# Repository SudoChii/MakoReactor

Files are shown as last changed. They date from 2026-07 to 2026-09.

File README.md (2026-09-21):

# Mako Reactor

CAD-as-code for layered leverless ("hitbox" style) fight controllers.

Describe where the buttons go, and Mako Reactor gives you back a stack of flat
plates you can send to a laser cutter, router, or 3D printer.

```python
import makoreactor as mr
from affine import Affine
from cadquery import exporters

layout = mr.FgcLeverless()
layout.layout_affine = Affine.translation(0, -13)

stack = mr.f1CapMako1.set(
    width=mr.in2mm(11.8),
    height=mr.in2mm(5),
    hole_deltax=300,
    layout=layout,
)

for i, plate in enumerate(stack.generate()):
    exporters.export(plate.edges(">Z"), f"layer{i}.dxf")
```

Or from a shell:

```bash
python -m makoreactor --layout fgc --width 11.8 --height 5 -o build/
```

## Install

Everything is available from conda-forge, so a single environment file covers it:

```bash
# replace mamba with conda if you don't have mamba
mamba env create -f environment.yml
mamba activate mako

pip install -e .
```

If you'd rather use pip alone, `pip install -e .` pulls `cadquery`, `numpy`, and
`affine` from PyPI; CadQuery ships the OpenCascade binaries as wheels.

Check it works:

```bash
pytest
```

## How it fits together

### Layouts (`makoreactor/layouts.py`)

A `Layout` holds button centres grouped by hand and function — `left_homerow`,
`right_homerow`, `left_thumb`, `right_thumb`, `misc` — and one affine per group
placing it on the plate. `layout_affine` shifts the whole cluster at once.

| layout | buttons | notes |
| --- | --- | --- |
| `CircleCapLeverless` | 20 | smash layout, Frame 1 circular caps |
| `Gccmx` | 22 | as above plus home/share, mimics Crane's GCCMX |
| `SquareCapLeverless` | 20 | smash layout, square MX keycaps |
| `Mako1Hadoe` | 20 | as above, right-hand eight dropped onto the home row |
| `WideGc` | 18 | as `Gccmx`, two thumb buttons a hand, no left pinky |
| `FgcLeverless` | 15 | traditional fighting-game layout, one thumb button |
| `SanwaFgcLeverless` | 15 | as above, spread out for 24/30mm Sanwa buttons |
| `FgcPlus` | 16 | as above on the smash spacing, pinky and two thumbs a hand, all 24mm |

The eight action buttons sit in two rows 22mm apart. In the smash layouts the
*bottom* row lines up with the four directionals, so the fingers rest low and
reach up; `Mako1Hadoe` drops the whole cluster by that one row pitch so the
*top* row lands on the home row instead.

`WideGc` keeps the smash spacing and the right hand's eight, and changes the
other three groups. The stock thumbs are lopsided — two buttons on the left, a
five-button c-stick on the right — so it cuts the right cluster back to its
bottom two, the same pair the left thumb already has, and both thumbs end up
with the same reach. The centre is Crane's, inherited from `Gccmx`: a row of
three on a 20mm pitch where the stock layout has one button. The left hand
loses its pinky — the outermost of its four, the same button `FgcLeverless`
drops — leaving three directionals. Eighteen buttons.

Dropping the pinky leaves the cluster 13mm right of the plate centre, since
nothing came off the right hand. Shift it back with
`layout.layout_affine = Affine.translation(-13.3, 0)` if that matters for the
plate you are cutting.

`layout.layout` is the flat list of centres in plate coordinates;
`layout.geom` is the same thing as cap outlines ready to cut.

### Parts (`makoreactor/parts/layered_leverless.py`)

Each part is a rounded rectangle with mounting holes, plus whatever it cuts:

| part | cuts |
| --- | --- |
| `Base` | nothing — solid bottom |
| `WireSpaceModelU` | interior frame for wiring, plus the USB-C breakout pocket |
| `Switchplate` | 14x14 switch mounts on every button centre |
| `F1CapFaceplate` | circular cap openings |
| `KeycapFaceplate` | square keycap openings |
| `Backplate` | cap openings, cosmetic top |
| `BrookWireSpace` | as `WireSpaceModelU`, deep enough to hang a Brook board in |
| `BrookSwitchplate` | as `Switchplate`, plus four board screws and a relief window |

Mounting holes are nested rectangles inset from the edge by `hole_offset`, each
one `hole_deltax` narrower than the last, until another would not fit. A 13.5"
plate at the default 275mm pitch gets eight holes; an 11.8" plate at 300mm gets
the four corners.

`WireSpaceModelU` carries the USB-C opening. Going inwards from the plate edge:
a `usbc_slot_width` slot the connector pokes through, then a
`usbc_pocket_width` x `usbc_pocket_depth` pocket that the small breakout PCB
sits in, with a `usbc_relief_radius` semicircle either side of it — tangent to
the pocket walls and centred on its top edge — so the board can be seated and
levered back out. Below that, `usbc_throat_width` runs the wires down into the
cavity between the two arms of the boss.

#### Housing a Brook board (`brookMako1`)

`brookMako1` is the same five layers with two of them swapped, for a build that
carries a Brook Gen-5X/UFB rather than ModelU boards alone. The board hangs
face-up under the switchplate on standoffs, and everything else follows from
that:

```python
stack = mr.brookMako1                  # WideGc layout, 14x6", two 1/4" spacers
for ok, why in stack.checks():
    print("ok " if ok else "BAD", why)
```

`BrookWireSpace` needs no new cutout — the layer is already an open frame — so
what it adds is *depth*. Plates come from sheet, so depth only arrives in whole
thicknesses of stock: `spacers()` rounds the board up to a whole number of 1/4"
layers and `part_depth()` never returns less, whatever `n_modelu` says. The
board then sits as low as it goes, and `standoff_length()` is the rest of the
depth — the standoffs to actually buy. At the defaults that is two spacers,
12.70mm, and 8.10mm standoffs.

Whatever the components reach above that has to go somewhere, which is
`BrookSwitchplate`. It cuts four screw holes on the board's mounting pattern
and a window over the middle of the board — the PCB outline pulled in by
`board_rim`, so a rim of material is left all the way round carrying those four
screws. The window goes clean through, because these plates are cut flat and
there is no such thing as a pocket here. At the defaults the components stand
2.90mm proud of the switchplate's underside and the plate is 3.175mm thick, so
the faceplate closes over them untouched. Three spacers instead of two would
swallow the board whole and the window could come off (`board_relief=False`).

`checks()` measures all of that, plus the things that depend on where the board
sits: clearance to the nearest switch mount, to the corner screws, to the cavity
wall and the corner pads, and that each of the four screws lands on material
rather than in a switch mount. `check()` raises instead, and the CLI runs it
before writing anything:

```bash
python -m makoreactor --stack brook -o build/
```

Swap the layout and the checks are what notice. `--layout fgc` puts the FGC
layout's action buttons straight through the board, and the run stops with
`BAD: board clears the nearest switch mount by -24.5mm` rather than cutting it.

**Two numbers here are assumptions, not datasheet.** Brook publishes neither the
mounting hole pattern nor a height, so `BrookBoard` assumes holes 3.5mm in from
each corner — an 89.01 x 38.01mm pattern, the same assumption
`SanwaBody.board_hole_inset` already made, with a test pinning the two together
— and an 11mm tallest component. Measure your board before cutting; both are
fields, and `component_height` is the one that decides whether the faceplate
stays closed.

### Sanwa parts (`makoreactor/parts/sanwa_fgc.py`)

The same idea built out of arcade parts instead of mechanical switches. Snap-in
buttons need a panel 2–3.9mm thick to grip, but a 320mm plate that thin flexes,
and a rear panel, a board mount and screw bosses are not flat — so the stack
splits into three cut plates and one printed body:

| part | is | carries |
| --- | --- | --- |
| `SanwaTopPlate` | 3mm, cut | the button holes, 24mm and 30mm |
| `SanwaSupportPlate` | 6mm, cut | the same holes 4mm wider; stiffens the top plate |
| `SanwaBody` | 36mm, printed in two | walls, rear panel, board holder, skirt, screw bosses |
| `SanwaBottomPlate` | 3mm, cut | closes the bottom |

Two stacks ship: `sanwaFgc` on the FGC layout (320 x 200mm) and `sanwaFgcPlus`
on `FgcPlus` (460 x 215mm), which puts the hands 200mm apart as the smash
layouts do and rests both of them on the same row.

`FgcPlus` is arranged around the **top** row of the right-hand eight being the
home row, where the fingers rest:

* the left hand gets four buttons — the mirror of the right hand's second row,
  pinky included — carried up one `row_pitch` so it lands level with the right
  hand's *top* row. Both hands rest at the same height.
* the thumbs sit exactly where the smash layouts put MX and MY — just inboard
  of the index finger and well below it — and stay there when the hands go up,
  so the reach is longer here than on those layouts: 87mm below the index
  button against Mako1's 69mm.
* the three menu buttons are off the face — they are on the back panel, and
  hanging them off one corner stopped the cluster centring. Put them back with
  `layout.misc_coords = FgcLeverless.misc_coords`.

The board sits under the right palm, outboard of the thumb cluster. That corner
is what sets the width: with the thumbs at MX/MY they take the inboard half of
it, and the cluster is centred, so the room has to come from both sides.

#### How it goes together

Nothing threads into plastic and nothing is glued. The printed body takes brass
**M3 heat-set inserts** — a 4.2mm hole 6mm deep, the standard seat for a
4.6 × 5.7mm insert — pressed in with a soldering iron before anything else
happens. Every screw is then an M3 machine screw into brass, and every insert
goes in from the face its screw comes from, so all of them are reachable on a
bare printed half.

`fasteners()` prints the schedule for whatever the stack is currently set to:

```
22 x M3 heat-set inserts, 4.2mm hole x 6mm deep
14 x M3 x 14 screws, down through both top plates into the body
 8 x M3 x 8 screws, up through the bottom plate
 4 x M3 x 8 self-tapping screws, up into the board standoffs
 2 x 4mm dowels x 10mm, locating the printed halves
```

Then, in order: dowel the two halves together, press the rear buttons and the
jack into the back panel, screw the board up into its standoffs from
underneath, snap the face buttons into the top plate and wire them, lay the
support plate on the body and the top plate on that, and run the long screws
down through both into the rim. The bottom plate goes on last, from below, and
is the only thing to take off to get at the board again.

#### Where the screws go

The rim pattern follows the chamfered outline in: **one screw per chamfer**
rather than one either side of it, then as many along each straight edge as it
takes to keep the spacing under `screw_pitch`. The top two plates pick up two
more over the board holder, so the middle of the span is fastened as well as
the edge.

The bottom plate does not repeat all of that. Nothing pushes on it and it
carries no buttons, so it takes a **subset** of the rim — the four corners plus
enough of the rest to keep its own spacing under `bottom_screw_pitch`. Every
screw it skips is a heat-set insert saved too. Between that and the single
corner screws, a `sanwaFgc` went from 32 fasteners to 22.

**The outline** is a rectangle with the corners chamfered off rather than
rounded, and both ends of every chamfer rounded — `corner_chamfer` and
`corner_fillet`. The cavity follows it in, so the wall stays an even thickness
the whole way round.

**The board hangs from the top of the cavity**, not off the floor: an 8mm slab
under the lid, the Brook on standoffs below it, and that same slab taking the
two middle screws. Pulling the bottom plate gets you at the board without
touching the button plates.

**The skirt** is a flange turned inwards round the bottom of the walls,
`skirt_width` deep into the cavity. The body is open underneath, which leaves
the printed halves floppy and the bottom plate spanning unsupported; the skirt
ties the walls together, carries the plate all the way round, and gives the
print a wide flat face. Its opening repeats the outline's treatment at a larger
scale — a chamfered rectangle with the chamfers rounded — and has to stay big
enough to pass the board through, since the board goes in from underneath.

**The back wall** puts the USB-C jack on the centreline in the Neutrik D-series
footprint (24mm bore, two M3 screws diagonally opposite it), with 24mm OBSF-24
buttons divided evenly either side — two and two by default,
`rear_button_count=6` for three a side, and the pitch closes up on its own so
the outermost button still lands on the straight part of the wall. Nothing back
there is bigger than a 24mm button; the 30mm one is the face thumb button, and
it is a 36mm wall. Neither a snap-in button nor the jack will fit that wall, so
it is relieved from the inside to `rear_panel_thickness` around each of them.

Each rear button gets a **release slot** either side of it, `tab_slot_width` x
`tab_slot_height`, running right up to the hole. A snap-in button's tabs are
behind the panel they grip, and once the case is shut there is no other way to
reach them; with the slots you can pinch the tabs through the wall and push the
button back out. The bezel covers most of each slot. They widen what a rear
button asks of the wall, so the screw and split placement works around them
too.

Where the screws can go along that edge is decided by what is mounted in it: a
button's body reaches 24.5mm past the wall, so a boss behind one would be inside
it. `rear_screw_points()` drops one into each bay between components wide enough
to take it, and leaves the ends to the side edges.

**The body prints in two pieces.** It does not fit a bed whole, so `halves()`
cuts it down `split_x()` — not down the middle, where the jack is, but through
the clear bay beside it. That position is derived from the rear panel rather
than fixed, so moving the buttons moves the split instead of stranding it in
one of them; `split_offset` pins it if you want. The halves locate on dowels
through the front and back walls and are clamped by the plates that screw into
both. `sanwaFgc` comes off a 220 x 220mm bed; `sanwaFgcPlus` is bigger and
wants 250 x 250.

Almost every dimension here is pinned by another one, so the assembly states
those constraints as checks rather than leaving them in a comment:

```python
for ok, why in mr.sanwaFgcPlus.checks():
    print("ok " if ok else "BAD", why)
```

`check()` raises instead, and both the CLI and the tests run it. It is what
caught the failures this design walked into: a rear button whose body passes
through a screw boss, a jack tucked under the corner where the misc buttons hang
down into the same space, a plate too shallow to keep rear button bodies clear
of the row in front of them — which is why it is 200mm deep rather than the
170mm the button layout alone needs — four corner screws left hanging in the air
once the corners were chamfered, and a board holder wide enough to reach a wall
only by cutting through the thumb cluster on the way.

```bash
python -m makoreactor --stack sanwa -o build/   # plates as DXF, body halves as STEP
```

### Sharing parameters

`LayeredAssembly.set(**kwargs)` pushes shared parameters into every layer that
accepts them and returns a new assembly, so stacks are cheap to fork:

```python
wide = mr.f1CapMako1.set(width=mr.in2mm(13.5), hole_deltax=275)
```

`generate()` returns the plates in stack order; `assemble()` returns a CadQuery
`Assembly` with them stacked along Z.

## Reference exports

`notebooks/mako1_fgc/layer{0..4}.dxf` were cut from real material and are
treated as the specification. `tests/test_reference_export.py` regenerates them
and compares outlines, mounting holes, button openings, and fillet arcs.

The parts module was never committed to this repo — it was reconstructed from
those exports, the notebook that produced them, and the earlier
`makogen/parts.py` in the git history. All five layers now regenerate exactly:
every entity count, every hole, and every arc matches to the hundredth of a
millimetre.

## Notebook and rendering

`notebooks/demo.ipynb` walks through layouts, building a stack, rendering it,
exporting DXFs, and a Pi Pico holder.

```bash
jupyter lab notebooks/demo.ipynb
```

Its `show()` helper prefers [jupyter-cadquery][jcq] for interactive OCP
rendering and falls back to a flat inline SVG when the viewer is missing or no
Jupyter server is reachable — so the notebook still runs headless under
nbconvert or nbclient.

[jcq]: https://github.com/bernhard-42/jupyter-cadquery

To get the 3-D viewer, use the environment that pins a matching OCP:

```bash
mamba env create -f environment-viewer.yml
mamba activate mako-viewer
pip install -e ".[viewer]"
```

jupyter-cadquery 4.0.2 targets OCP 7.8, which is what CadQuery 2.7 pins, so that
environment holds CadQuery one minor version back and resolves cleanly. If you
are already on CadQuery 2.8 (OCP 7.9), the viewer works there too, but you need
newer tessellation than jupyter-cadquery asks for — `pip` will report the pin
conflict, and it is safe to ignore:

```bash
pip install jupyter-cadquery
pip install --upgrade ocp-tessellate ocp-vscode
```

`LayeredAssembly.assemble()` is built for this: it stacks the layers along Z and
colours them so they can be told apart. Pass `explode=True` to load the viewer's
explode tool, then drag the animation slider under the render to pull the plates
apart and check that cutouts line up between layers.

```python
show(stack.assemble(), explode=True)
```

The explode distance is fixed at 2.5x by the viewer itself — three-cad-viewer's
`explode(duration=2, speed=1, scale=2.5)` is called with no arguments, and
jupyter-cadquery's `explode` is only a boolean that switches the tool on. If you
need the plates further apart, `assemble(gap=...)` spaces them in the model
instead, which also works without the viewer.

To send renders to a docked side panel instead of the cell output, call
`open_viewer("Mako", anchor="right")` once.

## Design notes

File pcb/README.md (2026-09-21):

# Mako1 switch PCB

The board that goes where the switchplate goes: same outline, same bolt
pattern, 20 key switches on the layout's own centres, everything else hanging
underneath in the space `WireSpaceModelU` already opens up.

Written in [atopile](https://github.com/atopile/atopile) — the circuit is a
`.ato` file, the footprints and the placement are generated from the same
numbers the plates are cut from.

```bash
python tools/build_parts.py             # footprints and symbols -> parts/
ato build                               # netlist + footprints
python tools/place.py --format json > tools/placement.json
python tools/place_pcb.py               # put them where the layout says
python tools/place.py --format check    # does the layout still fit
python tools/place.py --format stack    # does the board still fit the stack
```

`ato build` gives you the right parts and the right nets, but it stacks them in
a row at the origin — the placement is the second half of the job, and
`place_pcb.py` is what does it: every switch on its layout centre, the Pico and
the Model UD flipped to the back, the outline and the eight bolt holes drawn on
Edge.Cuts. Run it after any `ato build`; it sets absolute positions, so running
it twice changes nothing.

### If the board looks like everything is in a line

That is a board that has been built but not placed, and it is what both the
atopile 3D view and the layout viewer in VS Code will show you, faithfully:
every footprint sitting at the origin 10mm apart, and no board outline — which
is also why `kicad-cli` starts warning `Board outline is malformed`. Both
symptoms are the one cause.

atopile owns the netlist and the footprints; nothing in the `.ato` file says
where a part goes, and 0.15.8 has no placement trait and no post-build hook to
hang one on. So a build that starts from a layout it cannot match writes the
default row, and the placement is gone.

The extension makes this easy to hit: it watches the project and rebuilds on
its own when a file changes. So run the two together rather than separately —

```bash
tools/build.sh            # ato build, then place, then check
tools/build.sh --export   # ...and write the fab files
```

It finds its own tools, because none of the three is on PATH and two of them
are easy to get wrong — plain `python` finds miniforge's *base* environment,
which has no cadquery in it, so the script tests each candidate by trying to
import `makoreactor` rather than trusting the name. Override any of them if
your paths differ:

```bash
ATO=/path/to/ato PY=/path/to/python KICAD_CLI=/path/to/kicad-cli tools/build.sh
```

— and if the viewer ever shows the row again, `python tools/place_pcb.py` puts
it back. It sets absolute positions, so it is safe to run at any time, and a
plain `ato build` afterwards keeps them.

### Why the placement does not go through pcbnew

It edits the `.kicad_pcb` as text rather than driving KiCad's Python, and that
is deliberate. **KiCad 10 rewrites a board it saves**: it drops the net table
and writes pad nets by name only — `(net "gnd")` where atopile expects
`(net 12 "gnd")`. atopile 0.15.8 cannot read that back, so one save from
pcbnew ends the round trip and the next `ato build` fails on its own layout
file. Editing the text in place keeps the file in the dialect both tools read.

Opening the board in KiCad is fine. Saving it there is a one-way door: after
that, re-run `ato build` from a clean `layout/` if you need the netlist
regenerated.

### Installing the CLI

atopile is **not on conda-forge** — it is PyPI only, and every release since
0.14.1006 needs **Python 3.14**, so it cannot go in the `mako` environment
(3.11). It wants its own:

```bash
conda create -n ato -c conda-forge python=3.14
conda activate ato
pip install atopile
```

Two things to know about the CLI. It prints `0.15.8 is the last CLI release and
is in maintenance mode only` on every run — atopile has moved to the editor
extension and app.atopile.io for 0.16+, so this project is pinned to a CLI that
will not get fixes. And `ato validate` is broken in 0.15.8
(`ImportError: cannot import name 'front_end'`); `ato build` works, which is
what matters here.

## Where the wiring comes from

None of it is invented. Two sources, both worth reading before changing
anything:

**[The Model UD wiring diagram](https://github.com/HTangl/Model-UD)** (in its
`Pictures/` folder) gives the breakout-to-Pico connections, and this board
makes all of them:

| Model UD | Pico | why |
| --- | --- | --- |
| GND | GND | — |
| VSYS | VSYS | through the breakout's own Schottky |
| 5V | VBUS | raw bus voltage |
| GCD | GP28 | GameCube detect — without it the board is USB only |
| D+ / D− | TP3 / TP2 | by wire; the Pico has no header pins for these |

The diagram also says *connect AGND to GND*, which this does. The pads are
named as the board silkscreens them — `GCD`, `D-`, `D+`, `GND`, `3V`, `VSYS`,
`5V`.

**[HayBox](https://github.com/JonnyHaystack/HayBox)** `config/pico/config.cpp`
gives the button pinout, and this board uses it verbatim — LF1-4 on GP2-5,
RF1-8 on GP26/21/19/17/27/22/20/18, LT1-2 on GP6-7, RT1-5 on
GP14/15/13/12/16, MB1 on GP0, and GP28 as `joybus_data`. HayBox names buttons
by position rather than by function, which is exactly how the layout groups
them, so the mapping is one-to-one and a board built to it runs stock firmware
with no config edit. `place.py --format check` fails if the pinout drifts from
that list.

## What is on it

| | |
| --- | --- |
| 20 key switches | Choc v1 hotswap or soldered; MX soldered |
| Raspberry Pi Pico | on the back, on headers or soldered flat |
| Model UD / BirdD | on the back, USB-C |
| bolt holes | the stack's own eight, nothing added |

Direct wired: one GPIO per switch, common ground, no matrix and no diodes.
GP2040-CE turns on the RP2040's internal pull-ups, so that is the entire
circuit — which is why the interesting part of this project is the footprint
and the placement rather than the schematic.

## The switch footprint

One footprint takes either standard, because the low profile switches this
board is built around are not the only ones people have in a drawer:

| | Kailh Choc v1 | Cherry MX (and MX-pinned low profile) |
| --- | --- | --- |
| hotswap socket | yes, CPG135001S30 on the back | no |
| soldered direct | yes | yes |

**MX cannot be hotswapped here.** Its socket wants 3mm holes at the MX pin
positions, and those overlap the Choc socket's — 2.67 and 2.77mm apart, when
each needs 3mm. One standard or the other gets the sockets, and since the
brief was low profile by default, Choc gets them.

Getting both standards into one footprint at all comes down to which holes
share a net. MX pin 2 lands 2.67mm from Choc pin 1, closer than any two
pieces of copper on different nets could be, so the poles are paired to put
those two on the *same* net, where they are allowed to overlap. What is left
between opposite poles is **0.173mm**, at the Choc pin 2 / MX pin 2 pair.
That is above a 2-layer fab's 0.127mm floor and below anything comfortable, so
`tools/build_parts.py` recomputes it on every run and refuses to write a
footprint that closes it further.

## Pinout

GP2040-CE's stock Pico mapping, so the board runs on stock firmware without a
config. Switch numbers are layout order — the same order `mako1.ato` declares
them and `tools/place.py` places them.

| SW | GPIO | GP2040-CE | | SW | GPIO | GP2040-CE |
| --- | --- | --- | --- | --- | --- | --- |
| 1 | GP4 | Right | | 11 | GP8 | R2 |
| 2 | GP3 | Down | | 12 | GP20 | A1 |
| 3 | GP5 | Left | | 13 | GP2 | Up |
| 4 | GP13 | L1 | | 14 | GP21 | A2 |
| 5 | GP10 | B3 | | 15 | GP19 | R3 |
| 6 | GP11 | B4 | | 16 | GP18 | L3 |
| 7 | GP12 | R1 | | 17 | GP16 | S1 |
| 8 | GP9 | L2 | | 18 | GP14 | spare |
| 9 | GP6 | B1 | | 19 | GP15 | spare |
| 10 | GP7 | B2 | | 20 | GP17 | S2 / start |

GP14 and GP15 are the two c-stick positions this layout has and GP2040-CE's
default mapping does not; assign them in the web configurator.

## USB needs two wires

The Pico's D+ and D- do not come out on its 40-pin header — they are only on
the TP2/TP3 pads underneath it. So the Model UD's pair stops at a labelled
link beside the Pico footprint, and you run two short wires to those pads.
Every DIY Pico controller does this; there is no way to do it in copper alone
short of reflowing the Pico flat and trusting its test pads to land, which is
not a thing to ask of a hand-built board.

Power does not need wires: the Model UD's VSYS pin is VBUS through its own
Schottky, which is exactly what the Pico's VSYS wants, so it is a track.

## Fitting the stack

The switchplate it replaces is 3.175mm; a PCB is 1.6mm. **The stack loses
1.575mm** unless you make it up — either 1.6mm of spacer under the faceplate,
or order the board at 3.2mm, or let the keycaps sit that much lower, which
with low profile switches may be what you want anyway. Nothing in the layered
parts changes; `Switchplate` simply is not cut.

`tools/place.py` reports the clearances that matter on the current layout:

```
closest two switch footprints: +2.95mm
closest switch to a bolt hole: +9.91mm
closest switch to the board edge: +8.67mm
```

## What is checked, and what is not

**It builds.** `ato build` runs clean through every stage — instance graph,
electrical design, PCB update, post-PCB checks and all the report targets — and
writes `layout/default/default.kicad_pcb` with 22 footprints on it: 20
`MakoKeySwitch`, one Pico, one Model UD, designated SW1-SW20, U1 and J1.

The netlist has been read back out of that PCB and checked against the source:
all 20 switch A poles land on the GPIO `mako1.ato` names them to, all 20 B
poles share one net, and the Pico and Model UD agree on `gnd` and `vsys`. Nets
are named by function — `sw_right`, `sw_b1`, `usb_dp` — so the board reads
without cross-referencing.

Four things the first build turned up, in case they help elsewhere: trait
arguments cannot span lines; footprints must be the modern `(footprint ...)`
s-expression, not the legacy `(module ...)`; designators are only handed to
parts carrying `has_part_picked`, so a custom part needs it even though nothing
is being picked; and `override_net_name` only takes on a concrete package pin
(`pico.package.GND`), not on a locally declared interface, where the stdlib's
own `hv`/`lv` suggestions win.

**DRC is clean.** `kicad-cli pcb drc` reports 0 violations on the placed board
(KiCad 10.0.5). The 105 unconnected items it also reports are the nets: there
are no traces yet — `ato build` and `place_pcb.py` give you parts, nets and
placement, and routing is still yours to do.

Three things DRC caught that the earlier hand checks had missed, all now fixed:

- The switch footprint was drawn at the **19.05mm key pitch instead of the
  15.6mm switch body**, so on a layout whose thumb cluster sits at 18.5mm every
  one of those footprints overlapped its neighbour.
- `fits()` measured the straight-line distance between switch centres, which is
  the wrong measure for two axis-aligned squares — it read +2.95mm on a pair
  that overlapped by a millimetre. It measures the box gap now.
- The MX pin pad at 1.9mm came within 0.173mm of the Choc socket pad beside it,
  under the 0.2mm a 2-layer fab holds. At 1.8mm it clears by 0.223mm, with
  0.15mm of annular ring left.

The symbols are minimal hand-rolled `.kicad_sym` files, enough to carry pin
names.

## Exports

```bash
kicad-cli pcb export gerbers --output export/gerbers layout/default/default.kicad_pcb
kicad-cli pcb export drill   --output export/gerbers/ layout/default/default.kicad_pcb
kicad-cli pcb export dxf     --output export/outline --layers Edge.Cuts --output-units mm ...
kicad-cli pcb export step    --output export/mako1_pcb.step ...
```

The DXF and the STEP are the ones that answer *does it fit*, and they have been
checked against the plate rather than eyeballed: the exported outline is
**355.60 x 152.40mm** against the switchplate's 355.60 x 152.40, and its eight
bolt holes land on the plate's own pattern at 10mm. The STEP imports into
cadquery beside the rest of the stack.

Note `--output-units mm`: kicad-cli writes DXF in inches by default, which is
how an outline that is exactly right shows up as "14.00 x 6.00".

### The one thing that does not fit

`python tools/place.py --format stack` spells it out: the PCB is **1.6mm where
the switchplate was 3.175mm**, so there is 1.575mm to make up in the stack.

1.6mm is the right number, not a compromise — an MX or Choc switch clips into a
1.5mm plate, and that is what a board of this thickness gives it. The plate it
replaces was 1/8in because it was acrylic and had to be stiff on its own. So
either shim the difference, or set `Switchplate(depth=1.6)` and let the stack
come out 1.575mm shorter.

Everything that hangs underneath fits the 12.7mm wire space: the Pico soldered
flat is 2.4mm, on headers 11.0mm, the Model UD 5.0mm, and Choc sockets 1.85mm.
The Pico on headers is what wants `n_modelu=2` rather than 1.

The footprint geometry is checked, and against real sources: Cherry MX and
Kailh Choc drawings, cross-referenced with
[daprice/keyswitches.pretty](https://github.com/daprice/keyswitches.pretty)
(CC BY-SA 4.0), and the Model UD dimensions measured out of the Model BirdD
KiCad files in [HTangl/Model-UD](https://github.com/HTangl/Model-UD). Before
ordering, diff `parts/MakoKeySwitch/MakoKeySwitch.kicad_mod` against a
footprint from a library you trust — 0.173mm is not the place to find out a
number was off.

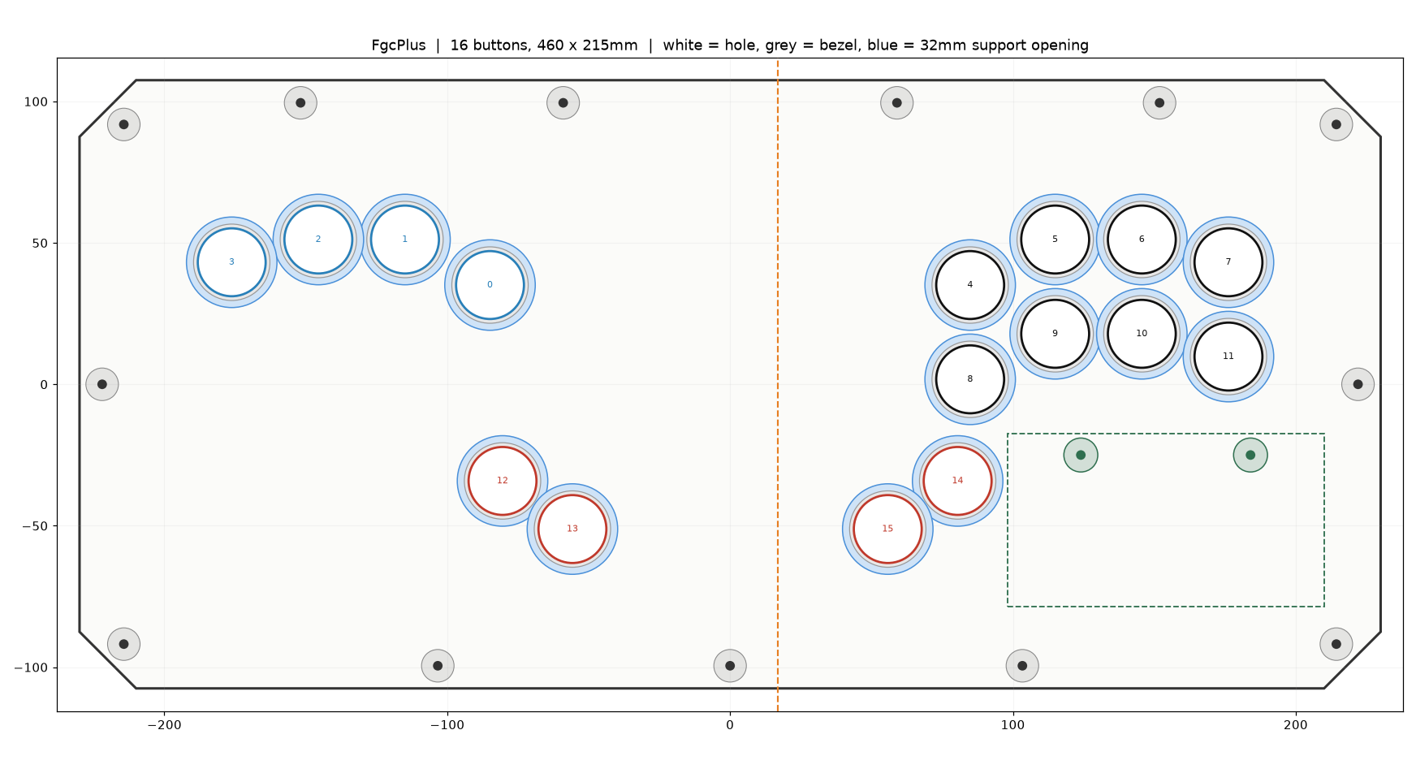
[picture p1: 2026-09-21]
plan_fgcplus.png

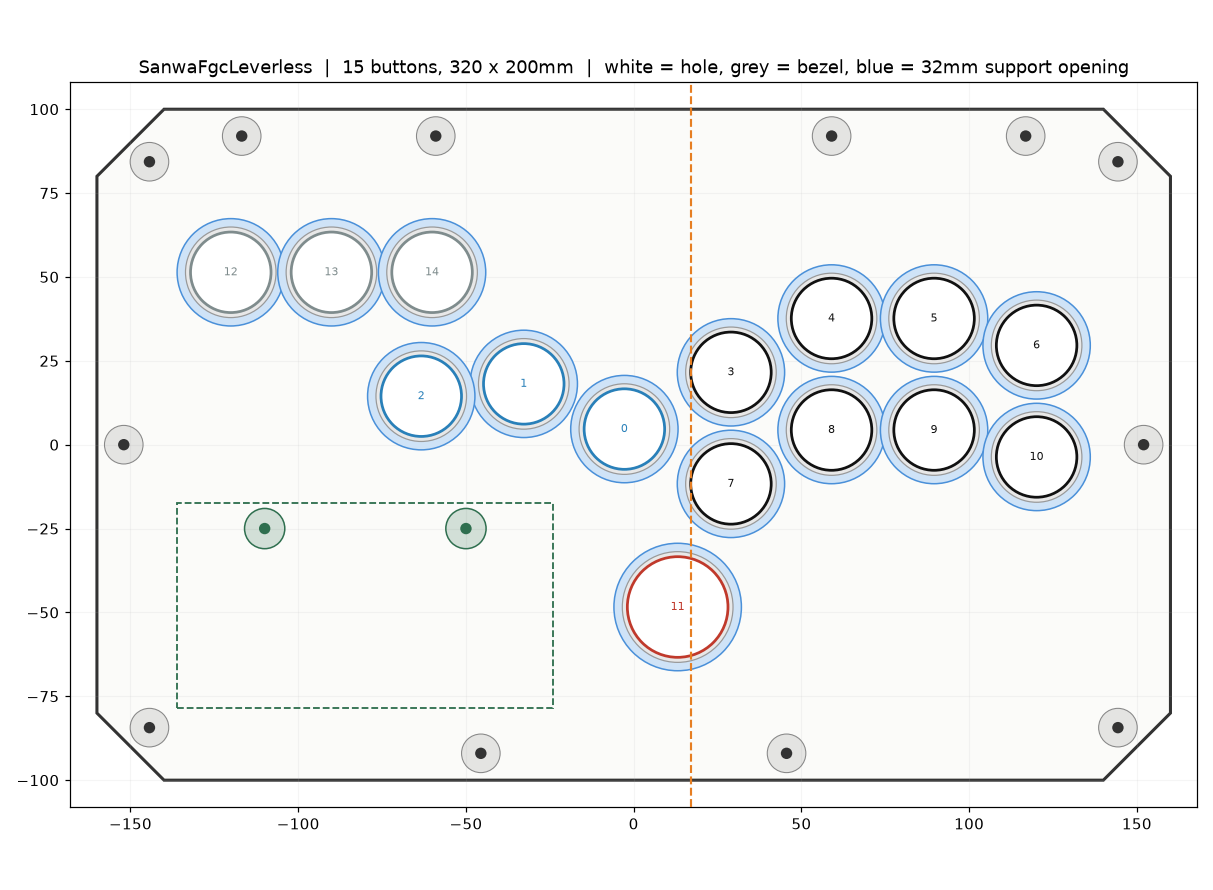
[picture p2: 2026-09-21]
plan_fgc.png

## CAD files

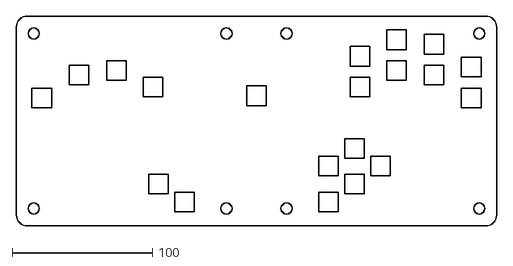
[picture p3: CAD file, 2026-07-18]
notebooks/artifacts/mako1/Switchplate.dxf
342.9 x 149.9

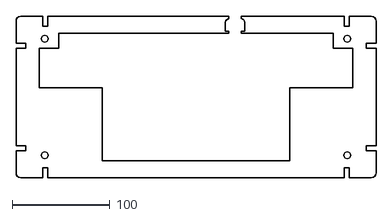
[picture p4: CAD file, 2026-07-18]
notebooks/artifacts/pcb_layer_2.dxf
368.3 x 165.1

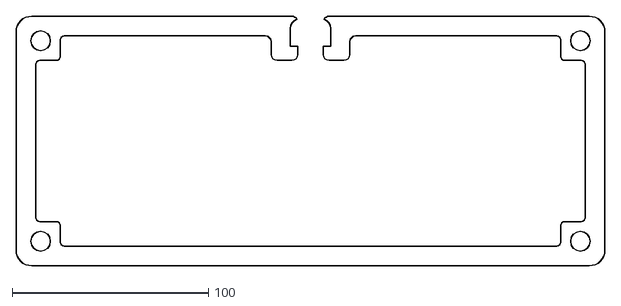
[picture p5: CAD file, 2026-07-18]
notebooks/mako1_fgc/layer1.dxf
299.7 x 127.0

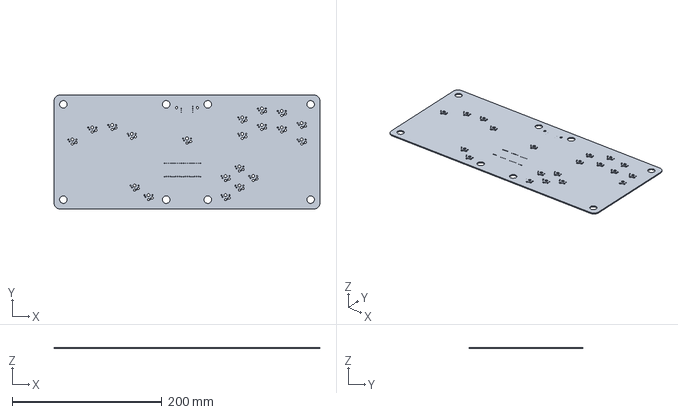
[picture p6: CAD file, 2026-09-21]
pcb/export/mako1_pcb.step
355.6 x 152.4 x 1.51 mm

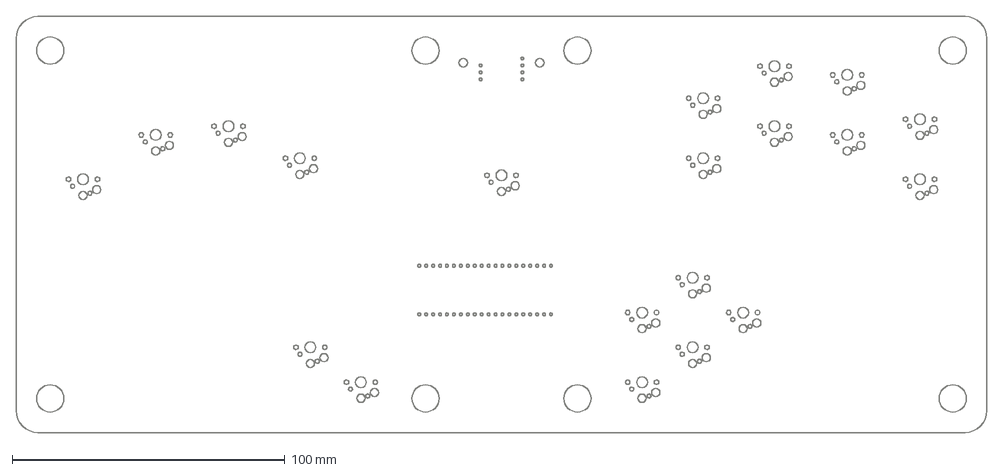
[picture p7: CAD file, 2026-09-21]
pcb/export/outline/mako1_filled-Edge_Cuts.dxf
355.6 x 152.4 mm

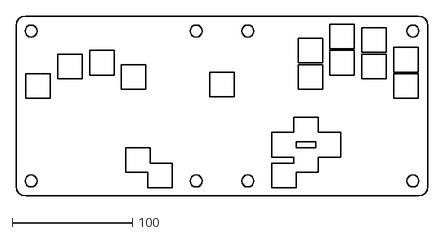
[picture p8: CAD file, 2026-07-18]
notebooks/artifacts/mako1/KeycapFaceplate.dxf
342.9 x 149.9

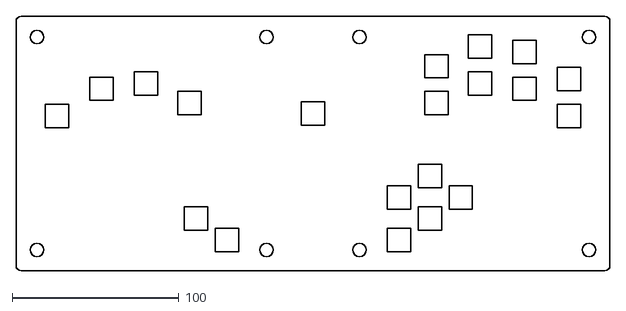
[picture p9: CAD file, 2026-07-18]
notebooks/artifacts/switch_plate.dxf
355.6 x 152.4

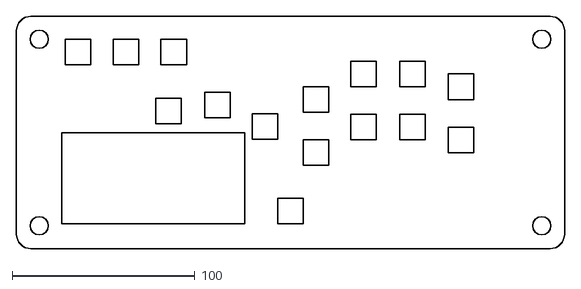
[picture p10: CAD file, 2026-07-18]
notebooks/mako1_fgc/layer2.dxf
299.7 x 127.0

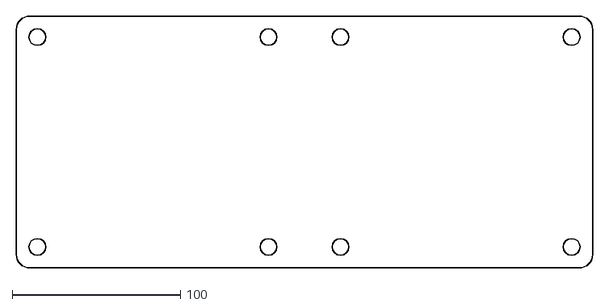
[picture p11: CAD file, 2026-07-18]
notebooks/artifacts/mako1/Base.dxf
342.9 x 149.9

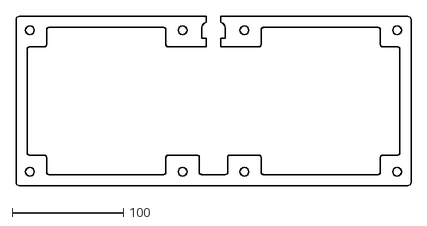
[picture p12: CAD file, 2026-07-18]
notebooks/artifacts/pcb_layer_1.dxf
355.6 x 152.4

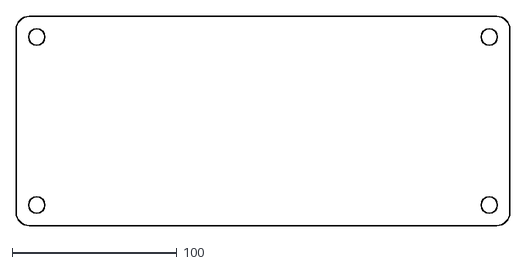
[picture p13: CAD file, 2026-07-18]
notebooks/mako1_fgc/layer0.dxf
299.7 x 127.0

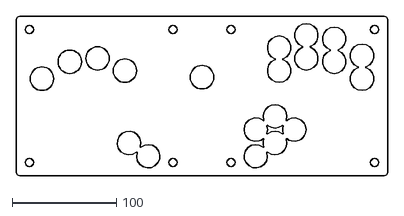
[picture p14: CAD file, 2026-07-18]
notebooks/artifacts/f1_cap_faceplate.dxf
355.6 x 152.4

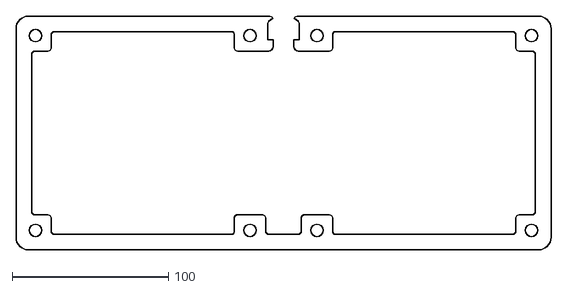
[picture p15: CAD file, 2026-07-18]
notebooks/artifacts/mako1/WireSpaceModelU.dxf
342.9 x 149.9

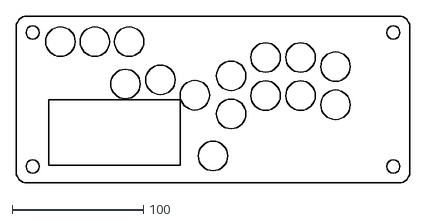
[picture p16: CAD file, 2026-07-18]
notebooks/mako1_fgc/layer3.dxf
299.7 x 127.0

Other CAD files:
notebooks/artifacts/pico_holder.stl
notebooks/mako1_fgc/layer4.dxf
notebooks/artifacts/keebcap_faceplate.dxf
notebooks/artifacts/dowel.dxf
notebooks/artifacts/bottom.dxf

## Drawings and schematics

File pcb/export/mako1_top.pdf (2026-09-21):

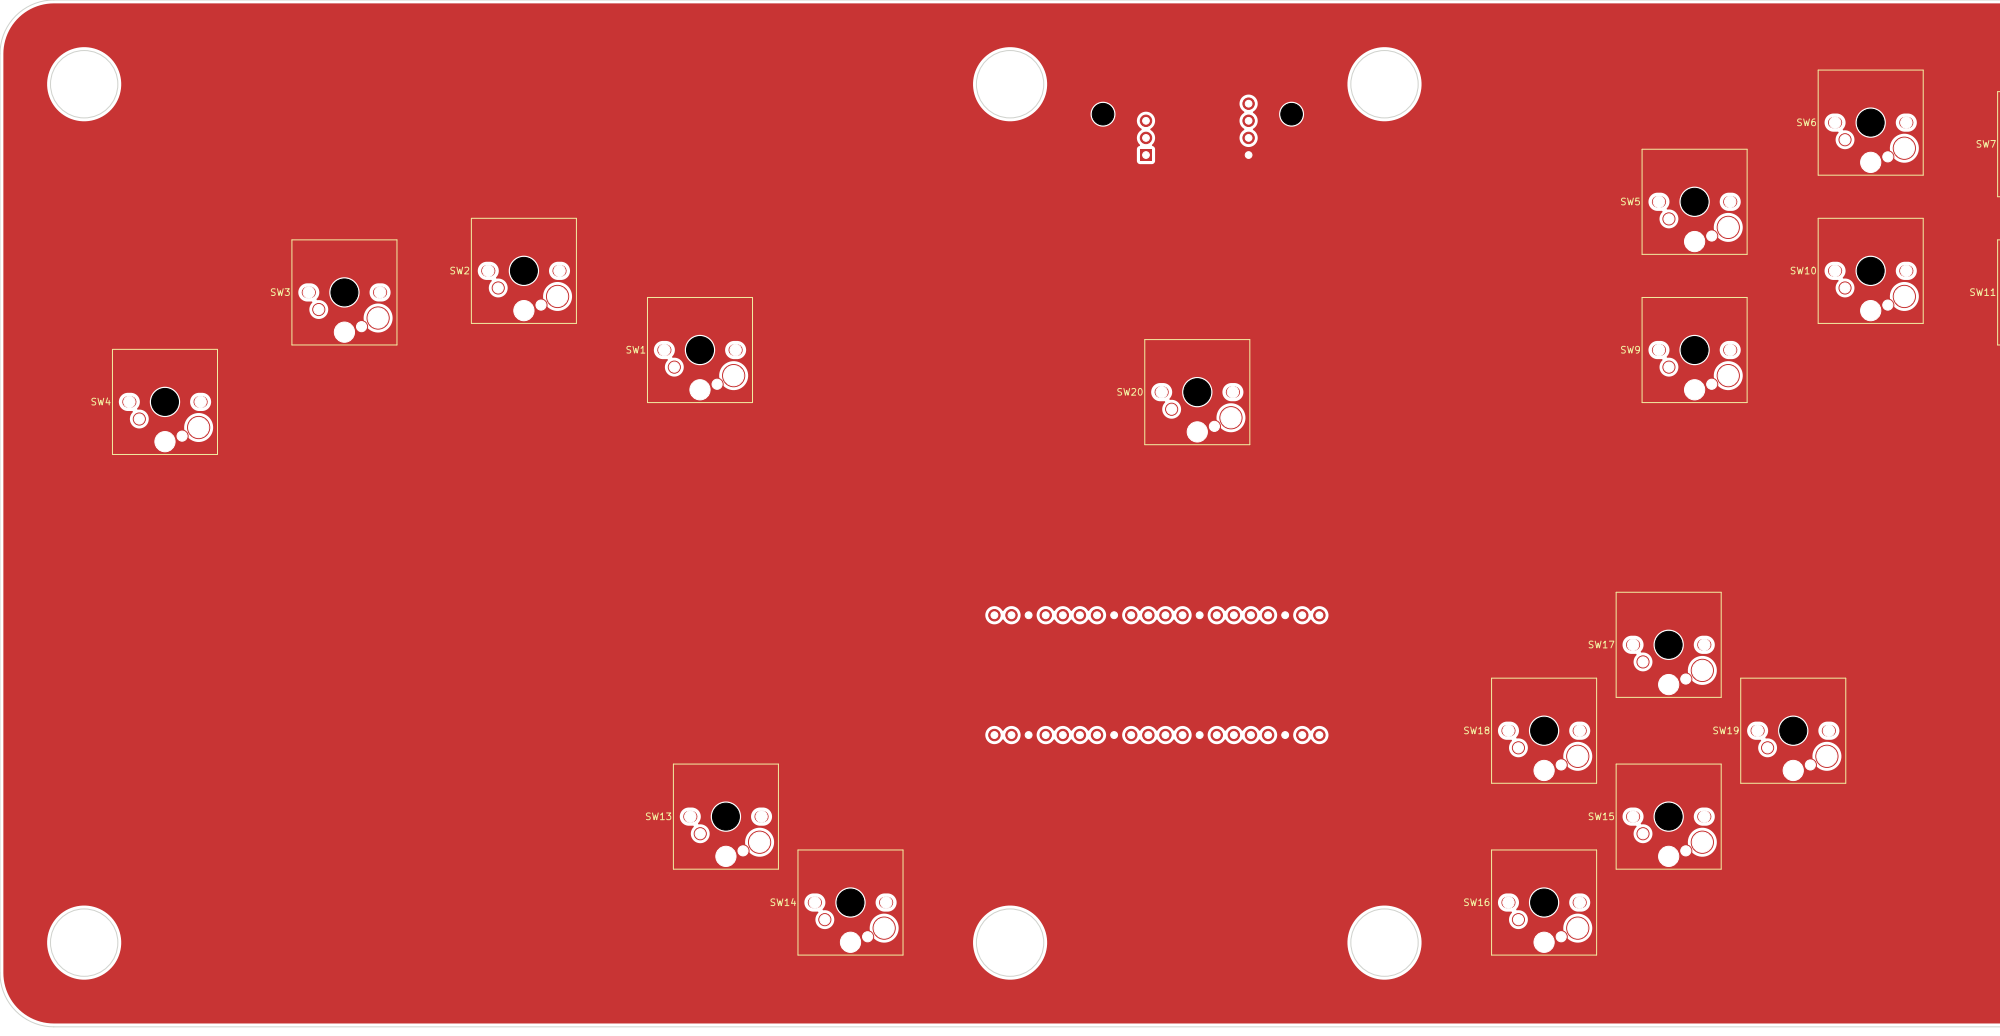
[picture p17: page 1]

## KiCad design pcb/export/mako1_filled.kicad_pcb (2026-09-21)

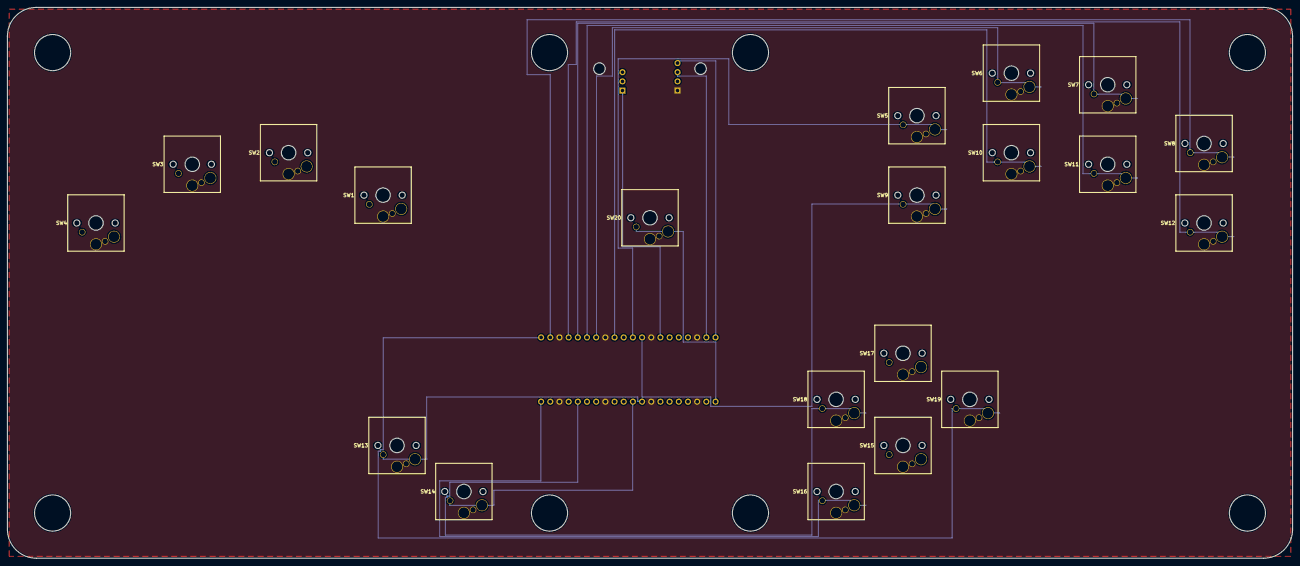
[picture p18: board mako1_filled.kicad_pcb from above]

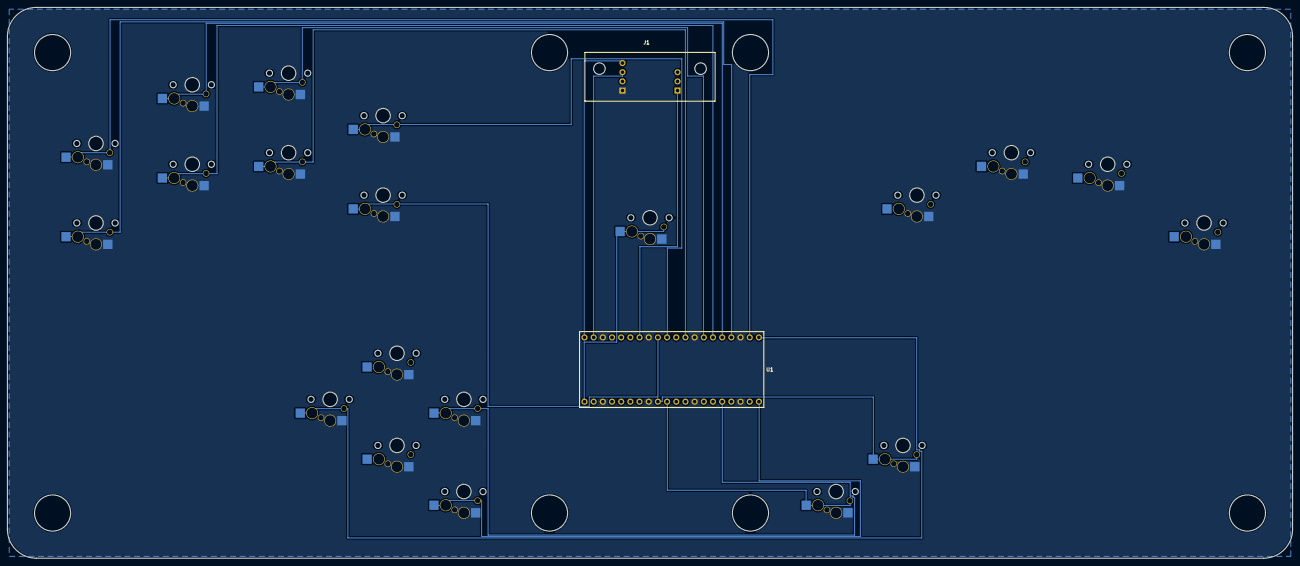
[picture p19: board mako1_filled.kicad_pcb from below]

Board: 2 copper layers, 355.6 x 152.4 mm, 22 parts (2 on the bottom side), 24 nets.

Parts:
J1: ModelUD
SW1, SW2, SW3, SW4, SW5, SW6, SW7, SW8, SW9, SW10, SW11, SW12, SW13, SW14, SW15, SW16, SW17, SW18, SW19, SW20: MakoKeySwitch
U1: RaspberryPiPico

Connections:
gnd: J1.GND, SW1.B, SW2.B, SW3.B, SW4.B, SW5.B, SW6.B, SW7.B, SW8.B, SW9.B, SW10.B, SW11.B, SW12.B, SW13.B, SW14.B, SW15.B, SW16.B, SW17.B, SW18.B, SW19.B, SW20.B, U1.AGND, U1.GND
joybus: J1.GCD, U1.GP28
sw_lf1: SW1.A, U1.GP2
sw_lf2: SW2.A, U1.GP3
sw_lf3: SW3.A, U1.GP4
sw_lf4: SW4.A, U1.GP5
sw_lt1: SW13.A, U1.GP6
sw_lt2: SW14.A, U1.GP7
sw_mb1: SW20.A, U1.GP0
sw_rf1: SW5.A, U1.GP26
sw_rf2: SW6.A, U1.GP21
sw_rf3: SW7.A, U1.GP19
sw_rf4: SW8.A, U1.GP17
sw_rf5: SW9.A, U1.GP27
sw_rf6: SW10.A, U1.GP22
sw_rf7: SW11.A, U1.GP20
sw_rf8: SW12.A, U1.GP18
sw_rt1: SW15.A, U1.GP14
sw_rt2: SW16.A, U1.GP15
sw_rt3: SW17.A, U1.GP13
sw_rt4: SW18.A, U1.GP12
sw_rt5: SW19.A, U1.GP16
vbus: J1.V5, U1.VBUS
vsys: J1.VSYS, U1.VSYS

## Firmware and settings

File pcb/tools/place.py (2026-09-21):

"""Place the board from the makoreactor layout.

The switch centres, the outline and the bolt pattern are already defined, in
``makoreactor`` -- the same numbers the plates are cut from.  Re-typing them
into KiCad would mean two sources of truth for the one thing that has to
match, so this reads them and writes them out instead.

    python tools/place.py --format report      # what goes where
    python tools/place.py --format json        # coordinates for apply_placement.py
    python tools/place.py --format dxf         # outline and holes, for the fab

Switch *i* here is ``switches[i]`` in ``mako1.ato``: both follow the order
``layout.layout`` gives, which is why the ato file lists them that way.
"""

from __future__ import annotations

import argparse
import pathlib
import sys

REPO = pathlib.Path(__file__).resolve().parent.parent.parent
sys.path.insert(0, str(REPO))

import makoreactor as mr  # noqa: E402

#: Side of the switch footprint's courtyard, from tools/footprints.py.  The
#: footprint is a square, so the gap between two of them is how far apart they
#: are along their *worst* axis -- not the straight-line distance between
#: centres, which is what this used to measure and which quietly passed a
#: thumb cluster whose footprints overlapped by a millimetre.
SWITCH_FOOTPRINT = 16.1


#: The mako1 FGC build: the stack in notebooks/mako1_fgc, whose switchplate
#: this board replaces.
def board(width_in: float = 14.0, height_in: float = 6.0,
          layout: str = "square") -> "mr.PlatePart":
    layouts = {
        "square": mr.SquareCapLeverless,
        "circle": mr.CircleCapLeverless,
        "gccmx": mr.Gccmx,
        "hadoe": mr.Mako1Hadoe,
    }
    return mr.Switchplate(
        width=mr.in2mm(width_in),
        height=mr.in2mm(height_in),
        layout=layouts[layout](),
    )


def positions(part) -> list[tuple[float, float]]:
    """Switch centres, in the order ``mako1.ato`` declares them."""
    return [tuple(point) for point in part.layout]


def report(part) -> str:
    points = positions(part)
    lines = [
        f"board      {part.width:.2f} x {part.height:.2f} mm, "
        f"corner radius {part.fillet_radius:.1f}",
        f"switches   {len(points)}",
        f"bolts      {len(part.mounting_points())} x "
        f"{part.hole_diameter:.1f}mm, the stack's own pattern",
        "",
        "  i  designator      x        y     group",
    ]
    groups = []
    for name in mr.GROUPS:
        groups += [name] * len(part.layout.placed(name))
    for index, ((x, y), group) in enumerate(zip(points, groups)):
        lines.append(f"{index:3d}  SW{index + 1:<2d}       {x:8.2f} {y:8.2f}   {group}")
    lines.append("")
    for x, y in part.mounting_points():
        lines.append(f"     bolt        {x:8.2f} {y:8.2f}")
    lines.append("")
    lines += fits(part)
    return "\n".join(lines)


#: Where the two boards that hang underneath go, in layout millimetres.
#:
#: The Model UD sits on the centreline against the back edge, because that is
#: where ``WireSpaceModelU`` already cuts the USB-C pocket -- x=0, and the
#: pocket runs from 6.25mm to 15.25mm in from the edge.  The Pico goes on its
#: side in the middle of the board rather than off in a corner: it is the far
#: end of twenty traces, and a corner would make every one of them cross the
#: whole board.  Both are checked against the layout by :func:`fits`.
BACK_PARTS = [
    {"address": "usb.package", "at": (0.0, 57.0), "rotation": 0,
     "size": (36.0, 13.5), "side": "back", "what": "Model UD, at the USB pocket"},
    {"address": "pico.package", "at": (-6.0, -24.0), "rotation": 90,
     "size": (21.0, 51.0), "side": "back", "what": "Pi Pico, middle of the board"},
]


#: What hangs under the board, in millimetres below its underside.  These are
#: the numbers that decide whether the stack still closes, so they are written
#: down rather than guessed at in a comment.
BELOW_BOARD = [
    ("MX switch pins", 3.3, "solder side of a 5-pin MX"),
    ("Choc hotswap socket", 1.85, "Kailh CPG135001S30, the deepest thing on a Choc build"),
    ("Pi Pico, soldered flat", 2.4, "its own board plus what is on the bottom of it"),
    ("Pi Pico, on 2.54mm headers", 11.0, "socket and header body, the tall option"),
    ("Model UD", 5.0, "its own board plus the USB-C shell"),
]


def stack(part) -> str:
    """Whether this board still fits the stack it is going into.

    The PCB replaces a 3.175mm plate with a 1.6mm one, which is not a detail:
    1.6mm is what a switch clips into, and 3.175mm is what the bolts were cut
    for.  Something has to give, and this says how much.
    """
    import makoreactor as mr

    space = mr.WireSpaceModelU(width=part.width, height=part.height, n_modelu=2,
                               layout=part.layout)
    pcb = 1.6
    lines = [
        "the board against the stack it replaces",
        "",
        f"  switchplate       {part.depth:.3f}mm  <- the PCB is {pcb:.2f}mm",
        f"  difference        {part.depth - pcb:+.3f}mm to make up",
        f"  wire space below  {space.part_depth():.2f}mm (n_modelu=2)",
        "",
        "  1.6mm is not a compromise, it is the right number: an MX or Choc",
        "  switch clips into a 1.5mm plate, which is what a PCB of this",
        "  thickness gives it.  The plate it replaces was 1/8in because it was",
        "  acrylic and had to be stiff.  So shim the difference rather than",
        "  thicken the board -- or set Switchplate(depth=1.6) and let the",
        f"  stack come out {part.depth - pcb:.3f}mm shorter.",
        "",
        "  under the board:",
    ]
    room = space.part_depth()
    for what, depth, note in BELOW_BOARD:
        fits = "fits" if depth < room else "DOES NOT FIT"
        lines.append(f"    {what:<28} {depth:5.2f}mm   {fits}, {room - depth:+.2f}mm spare   ({note})")

    tallest = max(depth for what, depth, _ in BELOW_BOARD if "headers" not in what)
    lines += [
        "",
        f"  worst case soldered flat is {tallest:.2f}mm into {room:.2f}mm, so the",
        "  stack closes; on headers the Pico is the tall part and wants the",
        "  full 12.7mm, which is why n_modelu=2 rather than 1.",
    ]
    return "\n".join(lines)


def placement(part) -> str:
    """The coordinates, as JSON for ``apply_placement.py``.

    KiCad's Python cannot import cadquery, so the numbers travel as a file
    rather than as an import -- but they are still generated from the part the
    plates are cut from, not typed twice.
    """
    import json

    return json.dumps({
        "pcb": "layout/default/default.kicad_pcb",
        "board": {
            "size": [part.width, part.height],
            "corner_radius": part.fillet_radius,
            "bolt_diameter": part.hole_diameter,
        },
        "switches": [[round(x, 4), round(y, 4)] for x, y in positions(part)],
        "bolts": [[round(x, 4), round(y, 4)] for x, y in part.mounting_points()],
        "back": [
            {"address": item["address"], "at": list(item["at"]),
             "rotation": item["rotation"], "side": item["side"], "what": item["what"]}
            for item in BACK_PARTS
        ],
    }, indent=2)


def kicad_script(part) -> str:
    """A script for KiCad's scripting console: places what ato has already
    netlisted, so the board matches the plates without hand-placing 20 parts.

    KiCad's Y axis points down and the plates' does not, so Y is negated here.
    """
    points = positions(part)
    lines = [
        '"""Run in KiCad: Tools > Scripting Console. Places the switches, the',
        'bolt holes and the outline from makoreactor\'s layout."""',
        "import pcbnew",
        "",
        "MM = pcbnew.FromMM",
        "board = pcbnew.GetBoard()",
        "",
        "SWITCHES = [",
    ]
    lines += [f"    ({x:.4f}, {y:.4f})," for x, y in points]
    lines += [
        "]",
        "BOLTS = [",
    ]
    lines += [f"    ({x:.4f}, {y:.4f})," for x, y in part.mounting_points()]
    lines += [
        "]",
        f"BOLT_DIAMETER = {part.hole_diameter}",
        f"BOARD = ({part.width}, {part.height}, {part.fillet_radius})",
        "",
        "origin = pcbnew.VECTOR2I(MM(BOARD[0] / 2), MM(BOARD[1] / 2))",
        "",
        "",
        "def find(index):",
        "    \"\"\"Match on the address ato stamps into each footprint, so a",
        "    reshuffled designator cannot silently move a button.\"\"\"",
        "    address = 'switches[%d]' % index",
        "    for footprint in board.GetFootprints():",
        "        try:",
        "            if footprint.GetProperty('atopile_address') == address:",
        "                return footprint",
        "        except Exception:",
        "            pass",
        "    return board.FindFootprintByReference('SW%d' % (index + 1))",
        "",
        "placed = 0",
        "for index, (x, y) in enumerate(SWITCHES):",
        "    footprint = find(index)",
        "    if footprint is None:",
        "        print('no footprint for switches[%d]' % index)",
        "        continue",
        "    footprint.SetPosition(pcbnew.VECTOR2I(MM(x), MM(-y)) + origin)",
        "    placed += 1",
        "",
        "# Bolt holes and the outline come in with the DXF this tool also",
        "# writes -- File > Import > Graphics, onto Edge.Cuts.",
        "",
        "pcbnew.Refresh()",
        "print('placed %d of %d switches' % (placed, len(SWITCHES)))",
    ]
    return "\n".join(lines) + "\n"


def dxf(part, out: pathlib.Path = pathlib.Path("board_outline.dxf")) -> str:
    """Outline and bolt holes as DXF, from the same part the plates are cut
    from -- this is the board shape, for KiCad's Edge.Cuts or for the fab."""
    from cadquery import exporters

    plate = part._cut_mounting_holes(part.blank())
    exporters.export(plate.edges(">Z"), str(out))
    return f"wrote {out} ({out.stat().st_size} bytes)"


def fits(part) -> list[str]:
    """Whether the switches actually clear each other and the bolts.

    The footprint is 19.05mm square and the layout was drawn for 20.5mm caps,
    so this should never be tight -- but the layout is a parameter, and a
    tighter one would put copper through copper.
    """
    import math

    points = positions(part)
    half = SWITCH_FOOTPRINT / 2
    notes = []

    def box_gap(a, b, size=SWITCH_FOOTPRINT):
        """How far apart two axis-aligned squares are -- negative if they
        overlap."""
        return max(abs(a[0] - b[0]), abs(a[1] - b[1])) - size

    gap = min(box_gap(a, b) for i, a in enumerate(points) for b in points[i + 1:])
    notes.append(f"closest two switch footprints: {gap:+.2f}mm")

    # The caps have to clear each other too, and they are wider than the
    # switch.  Choc caps are 17.5mm; MX caps are 18mm and this layout puts
    # some buttons 18.5mm apart, so MX is the tighter of the two.
    for cap, what in ((17.5, "Choc keycaps"), (18.0, "MX keycaps")):
        caps = min(box_gap(a, b, cap)
                   for i, a in enumerate(points) for b in points[i + 1:])
        notes.append(f"closest two {what}: {caps:+.2f}mm")

    bolt = min(
        math.dist(point, hole) - half - part.hole_diameter / 2
        for point in points for hole in part.mounting_points()
    )
    notes.append(f"closest switch to a bolt hole: {bolt:+.2f}mm")

    edge = min(
        min(part.width / 2 - abs(x), part.height / 2 - abs(y)) - half
        for x, y in points
    )
    notes.append(f"closest switch to the board edge: {edge:+.2f}mm")

    # The two boards underneath have to miss the switch bodies and the bolts
    # as well -- they are on the other side, but the through-holes are not.
    for item in BACK_PARTS:
        cx, cy = item["at"]
        w, h = item["size"]
        if item["rotation"] % 180:
            w, h = h, w
        near_switch = min(
            math.hypot(max(abs(x - cx) - w / 2, 0), max(abs(y - cy) - h / 2, 0)) - half
            for x, y in points
        )
        near_bolt = min(
            math.hypot(max(abs(x - cx) - w / 2, 0), max(abs(y - cy) - h / 2, 0))
            - part.hole_diameter / 2
            for x, y in part.mounting_points()
        )
        inside = min(part.width / 2 - abs(cx) - w / 2, part.height / 2 - abs(cy) - h / 2)
        notes.append(f"{item['what']}: {near_switch:+.2f}mm to a switch, "
                     f"{near_bolt:+.2f}mm to a bolt, {inside:+.2f}mm inside the edge")
        gap = min(gap, near_switch, near_bolt, inside)

    if min(gap, bolt, edge) < 0:
        notes.append("FAIL: something overlaps -- the layout will not fit this board")
    return notes


def wiring(part) -> list[str]:
    """Check mako1.ato against the layout: one switch per button, one GPIO
    each, and no GPIO used twice.

    The mapping is written out by hand in the ato file -- it has to be, since
    it is a choice about which button does what -- so this is the check that
    the hand-written part still lines up with the generated part.
    """
    import re

    source = (pathlib.Path(__file__).parent.parent / "mako1.ato").read_text()
    used = re.findall(r"switches\[(\d+)\]\.A ~ pico\.gpio\[(\d+)\]", source)
    switches = {int(sw) for sw, _ in used}
    gpios = [int(gp) for _, gp in used]

    notes = [f"mako1.ato wires {len(used)} switches to {len(set(gpios))} GPIOs"]
    expected = len(positions(part))
    if switches != set(range(expected)):
        missing = sorted(set(range(expected)) - switches)
        notes.append(f"FAIL: layout has {expected} buttons; "
                     f"switches {missing} are not wired")
    if len(gpios) != len(set(gpios)):
        doubled = sorted({gp for gp in gpios if gpios.count(gp) > 1})
        notes.append(f"FAIL: GP{doubled} wired to more than one switch")
    for gp in gpios:
        if gp in (23, 24, 25) or gp > 28:
            notes.append(f"FAIL: GP{gp} is not on the Pico's header")

    # The mapping is not free: it is HayBox's own config/pico, so a board built
    # to this pinout runs stock firmware with no config edit.  GP28 is not a
    # button -- HayBox uses it as joybus_data, which is the GameCube detect
    # line from the Model UD.
    haybox = {2, 3, 4, 5, 26, 21, 19, 17, 27, 22, 20, 18, 6, 7, 14, 15, 13, 12, 16, 0}
    if set(gpios) != haybox:
        extra = sorted(set(gpios) - haybox)
        missing = sorted(haybox - set(gpios))
        notes.append(f"FAIL: pinout has drifted from HayBox config/pico "
                     f"(extra {extra}, missing {missing})")
    if 28 in gpios:
        notes.append("FAIL: GP28 is HayBox's joybus_data, not a button")
    if not any(note.startswith("FAIL") for note in notes):
        notes.append("ok: every button has a GPIO and no GPIO is shared")
    return notes


def main(argv=None) -> int:
    parser = argparse.ArgumentParser(description=__doc__)
    parser.add_argument("--format", default="report",
                        choices=["report", "json", "stack", "kicad", "dxf", "check"])
    parser.add_argument("--width", type=float, default=14.0, help="inches")
    parser.add_argument("--height", type=float, default=6.0, help="inches")
    parser.add_argument("--layout", default="square",
                        choices=["square", "circle", "gccmx", "hadoe"])
    args = parser.parse_args(argv)

    part = board(args.width, args.height, args.layout)
    if args.format == "check":
        notes = fits(part) + wiring(part)
        print("\n".join(notes))
        return 1 if any(note.startswith("FAIL") for note in notes) else 0

    print({"report": report, "json": placement, "stack": stack,
           "kicad": kicad_script, "dxf": dxf}[args.format](part))
    return 0


if __name__ == "__main__":
    raise SystemExit(main())

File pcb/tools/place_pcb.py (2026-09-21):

"""Place the board from the layout, by editing the PCB file directly.

This does what KiCad's own Python would do -- move every footprint onto its
layout centre, flip the two boards that hang underneath, draw the outline and
the bolt holes -- but without going through ``pcbnew``, and that is deliberate.

KiCad 10 rewrites a board it saves: it drops the net table and writes pad nets
by name only (``(net "gnd")`` rather than ``(net 12 "gnd")``).  atopile 0.15.8
cannot read that back, so a single save from pcbnew ends the round trip -- the
next ``ato build`` fails on its own layout file.  Editing the text in place
keeps the file in the dialect both tools read, so the loop stays open:

    ato build            # netlist and footprints
    place_pcb.py         # where everything goes
    ato build            # still reads its own file

Coordinates come from ``placement.json``, which ``place.py`` writes out of
``makoreactor`` -- the same numbers the plates are cut from.

    python tools/place_pcb.py [--pcb path] [--plan tools/placement.json]
"""

from __future__ import annotations

import argparse
import json
import math
import pathlib
import re

#: Layers that swap when a footprint moves to the other side of the board.
FLIPPED = {
    "F.Cu": "B.Cu", "B.Cu": "F.Cu",
    "F.SilkS": "B.SilkS", "B.SilkS": "F.SilkS",
    "F.Mask": "B.Mask", "B.Mask": "F.Mask",
    "F.Paste": "B.Paste", "B.Paste": "F.Paste",
    "F.CrtYd": "B.CrtYd", "B.CrtYd": "F.CrtYd",
    "F.Fab": "B.Fab", "B.Fab": "F.Fab",
}


def block_at(text: str, start: int) -> tuple[int, int]:
    """The span of the s-expression beginning at ``start``."""
    depth = 0
    for i in range(start, len(text)):
        if text[i] == "(":
            depth += 1
        elif text[i] == ")":
            depth -= 1
            if depth == 0:
                return start, i + 1
    raise ValueError("unbalanced s-expression")


def blocks(text: str, tag: str):
    """Spans of every ``(tag ...)`` in ``text``, outermost first."""
    for match in re.finditer(r"\(%s[\s\n]" % re.escape(tag), text):
        yield block_at(text, match.start())


def footprint_spans(text: str) -> dict[str, tuple[int, int]]:
    """Footprint spans keyed by the address ato stamps into each one.

    Addresses rather than designators: a rebuild is free to renumber SW7, and
    a silently moved button is the one mistake this whole file exists to
    avoid.
    """
    found = {}
    for start, end in blocks(text, "footprint"):
        source = text[start:end]
        address = re.search(r'\(property "atopile_address" "([^"]+)"', source)
        if address:
            found[address.group(1)] = (start, end)
    return found


def to_board(point, size) -> tuple[float, float]:
    """Layout millimetres to board millimetres.

    The plates put the origin at the middle of the board with +Y towards the
    far edge; KiCad puts it at the top left corner with +Y downwards.
    """
    width, height = size
    return point[0] + width / 2.0, height / 2.0 - point[1]


def mm(value: float) -> str:
    text = ("%.4f" % value).rstrip("0").rstrip(".")
    return "0" if text in ("-0", "") else text


def move(source: str, position, rotation: float) -> str:
    """Set a footprint's position and angle."""
    x, y = position
    at = re.search(r"\(at [-\d.]+ [-\d.]+(?: [-\d.]+)?\)", source)
    placed = "(at %s %s%s)" % (mm(x), mm(y), " %s" % mm(rotation) if rotation else "")
    return source[:at.start()] + placed + source[at.end():]


def flip(source: str) -> str:
    """Move a footprint to the back of the board.

    Mirrors it about its own Y axis and swaps every front layer for its back
    counterpart, which is what KiCad does when you press F -- the pads have to
    end up on back copper, not just the outline on back silk.
    """
    def mirror_x(match):
        return "(at %s %s%s)" % (mm(-float(match.group(1))), match.group(2),
                                 match.group(3) or "")

    def mirror_point(match):
        return "(%s %s %s)" % (match.group(1), mm(-float(match.group(2))), match.group(3))

    body = source
    # Everything inside a footprint is relative to it, so mirroring is just a
    # sign flip on x -- except the footprint's own (at ...), which is where it
    # sits on the board and is set by move().
    head, rest = body.split("\n", 1)
    rest = re.sub(r"\(at ([-\d.]+) ([-\d.]+)( [-\d.]+)?\)", mirror_x, rest)
    rest = re.sub(r"\((start|end|center|mid) ([-\d.]+) ([-\d.]+)\)", mirror_point, rest)
    rest = re.sub(r'"(F|B)\.(Cu|SilkS|Mask|Paste|CrtYd|Fab)"',
                  lambda m: '"%s"' % FLIPPED["%s.%s" % (m.group(1), m.group(2))], rest)
    return head + "\n" + clear_reference(mirror_text(rest))


def clear_reference(source: str) -> str:
    """Put the designator outside the footprint's own outline.

    ato positions reference fields itself, and on the two big boards that lands
    it on top of their silkscreen -- which KiCad counts as an overlap, and
    which is unreadable in any case.  The outline is right there in the
    footprint, so put the text just above it.
    """
    ys = [float(m.group(2)) for m in
          re.finditer(r"\((?:start|end) ([-\d.]+) ([-\d.]+)\)", source)]
    if not ys:
        return source
    # 2.5mm, not 1.4: KiCad measures the text's whole box, which is
    # taller than the 1mm glyphs, and counts the margin as an overlap.
    top = min(ys) - 2.5

    found = source.find('(property "Reference"')
    if found < 0:
        return source
    start, end = block_at(source, found)
    block = source[start:end]
    block = re.sub(r"\(at [-\d.]+ [-\d.]+( [-\d.]+)?\)",
                   lambda m: "(at 0 %s%s)" % (mm(top), m.group(1) or ""), block, count=1)
    return source[:start] + block + source[end:]


def mirror_text(source: str) -> str:
    """Mirror any text that came along to the back.

    Text on back copper reads backwards unless it is mirrored; KiCad's DRC
    calls unmirrored text on a back layer a violation, and it is right --
    a designator you cannot read is not doing its job.
    """
    out, index = [], 0
    while True:
        found = source.find("(effects", index)
        if found < 0:
            out.append(source[index:])
            return "".join(out)
        start, end = block_at(source, found)
        block = source[start:end]
        if "(justify" in block:
            # Keep whatever alignment it already had and add the mirror to it:
            # a reference that is right-aligned still needs to read the right
            # way round on the back.
            if "mirror" not in block:
                block = re.sub(r"\(justify ([^)]*)\)", r"(justify \1 mirror)", block, count=1)
        else:
            indent = re.match(r"[\t ]*", source[source.rfind("\n", 0, start) + 1:]).group(0)
            block = block[:-1].rstrip() + "\n%s\t(justify mirror)\n%s)" % (indent, indent)
        out.append(source[index:start])
        out.append(block)
        index = end
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

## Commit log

2026-07-18 Snapshot repo state before CadQuery API repair work.
    Preserves the current working tree as-is prior to restoring the missing parts module and fixing import/runtime breakage.
    [Base.dxf, KeycapFaceplate.dxf, Switchplate.dxf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]
2026-07-18 Restore layered leverless parts and fix package imports.
    Reconstruct the missing parts module from notebook usage and artifact dimensions, stop gitignore from excluding makoreactor/parts, and update CadQuery dependency pins for current 2.x APIs.
